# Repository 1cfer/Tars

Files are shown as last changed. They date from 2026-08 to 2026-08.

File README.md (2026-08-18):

# TARS — Sistema Modular de Monitoreo Ambiental Portátil basado en ESP32

Dispositivo modular de monitoreo ambiental para interiores, basado en ESP32, con pantalla OLED, navegación por botón físico y firmware gobernado por una máquina de estados. Envía sus datos periódicamente a la plataforma en la nube MOREHA, construida sobre el estándar FIWARE. Desarrollado en el Semillero AgeVital, Universidad Pontificia Bolivariana.







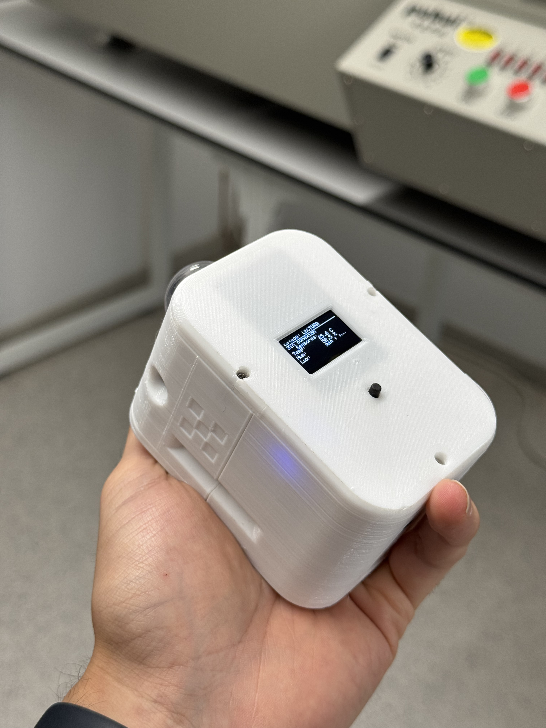
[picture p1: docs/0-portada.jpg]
TARS - vista de portada


## Descripción

TARS mide temperatura, humedad, luminosidad y ruido, y muestra los datos en tiempo real en una pantalla OLED con navegación por botón. El firmware usa una arquitectura de máquina de estados modular, y los datos se transmiten de forma segura hacia `moreha.com.co` mediante autenticación OAuth2 y paso por PEP Proxy, siguiendo el flujo de FIWARE (Keyrock → Wilma → Orion Context Broker).

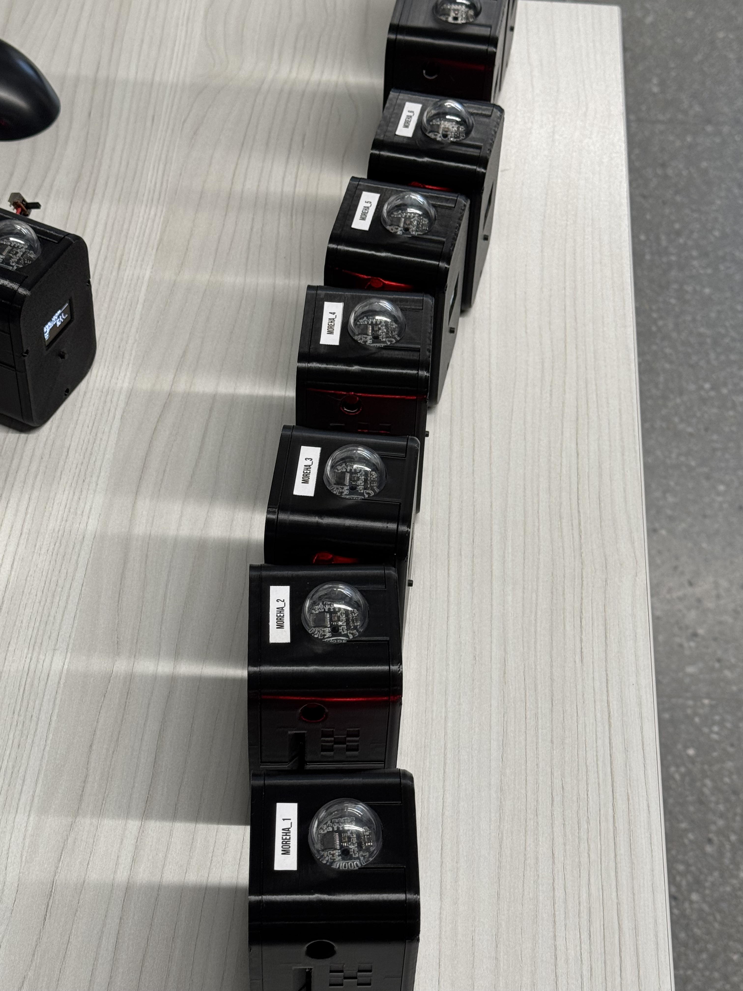
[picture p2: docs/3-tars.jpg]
Lote de dispositivos TARS ensamblados


## Características técnicas

- 🌡️ Temperatura y humedad (HDC1080, I2C)
- 💡 Luminosidad calibrada (DFRobot B-LUX-V30B, con filtro de mediana + descarte de picos)
- 🔊 Nivel de ruido (sensor analógico calibrado)
- 🧪 *(Experimental)* Calidad de aire — PM1.0 / PM2.5 / PM10 (DFRobot SEN0460), en evaluación energética y de laboratorio
- 🔌 Modularidad y expansión por bus I2C: espacio físico y líneas disponibles en la placa para incorporar nuevos sensores
- 🖥️ Pantalla OLED con navegación multi-pantalla por botón físico (pulsación corta/larga)
- 📡 Conectividad IoT industrial: envío periódico con autenticación OAuth2 y PEP Proxy

### Expansión por bus I2C

La placa reserva espacio físico y líneas de conexión libres para incorporar fácilmente un sensor adicional, siempre que use el protocolo I2C.

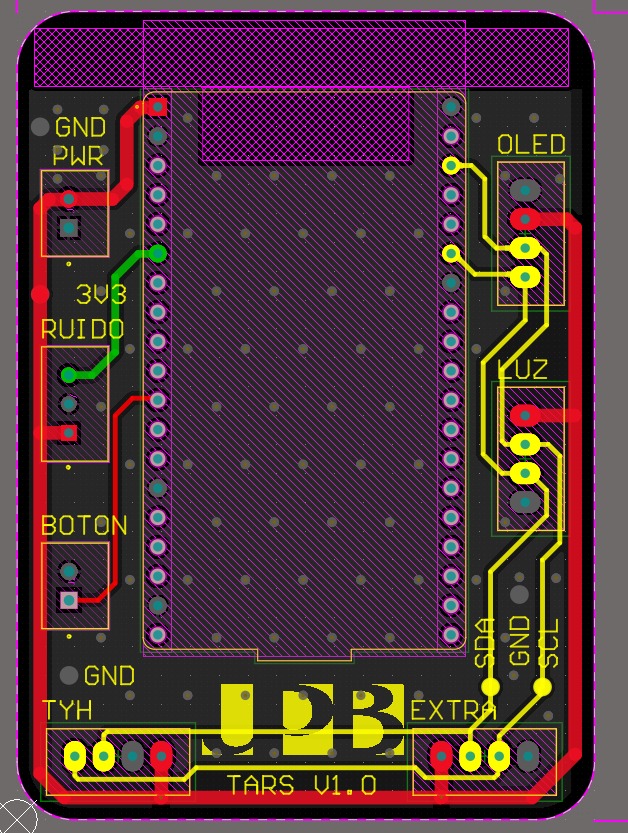
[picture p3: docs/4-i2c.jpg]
Puerto I2C libre para expansión de sensores


### Sensor de calidad de aire (experimental)

Integración en curso del sensor PM1.0 / PM2.5 / PM10 (DFRobot SEN0460), actualmente en fase de evaluación energética y de laboratorio.

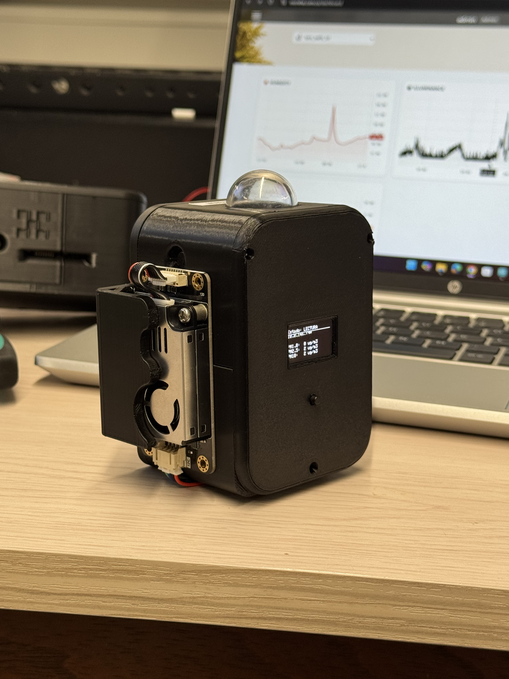
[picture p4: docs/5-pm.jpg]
TARS con sensor experimental de calidad de aire conectado


## Evolución del hardware

TARS partió de un prototipo de pruebas hasta llegar a la PCB con la que operan actualmente todos los dispositivos.

<table>
<tr>
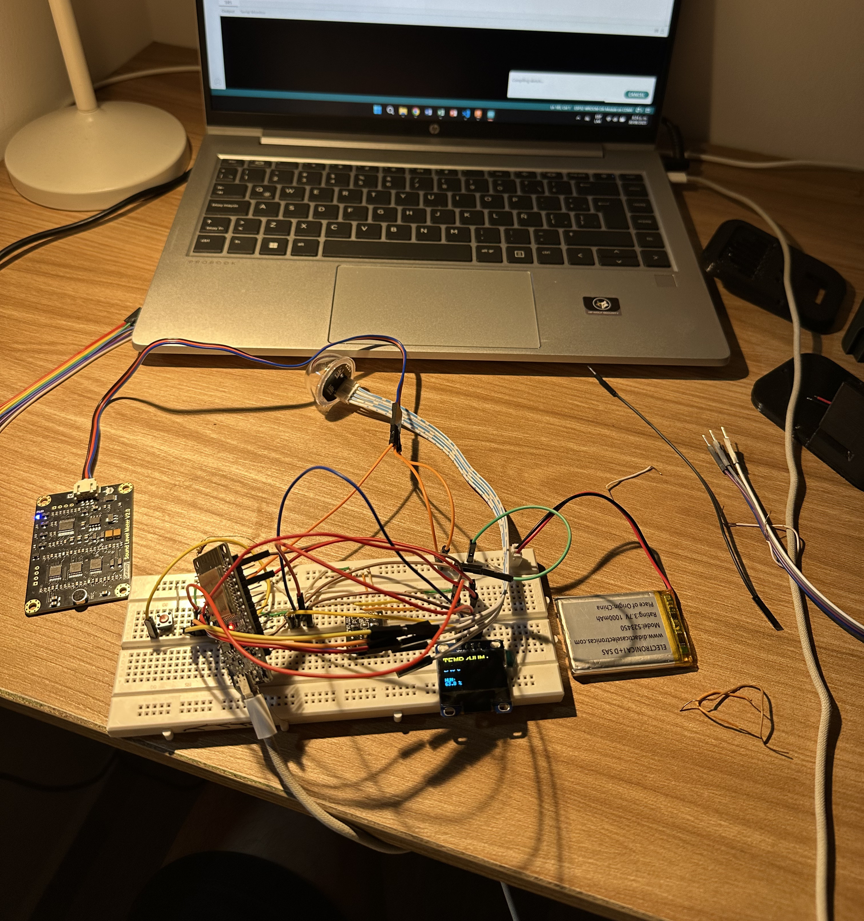
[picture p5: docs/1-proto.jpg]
Prototipo en breadboard
<td align="center"><br/><sub><strong>Fase 1</strong> — Prototipo inicial en breadboard, cableado suelto</sub></td>
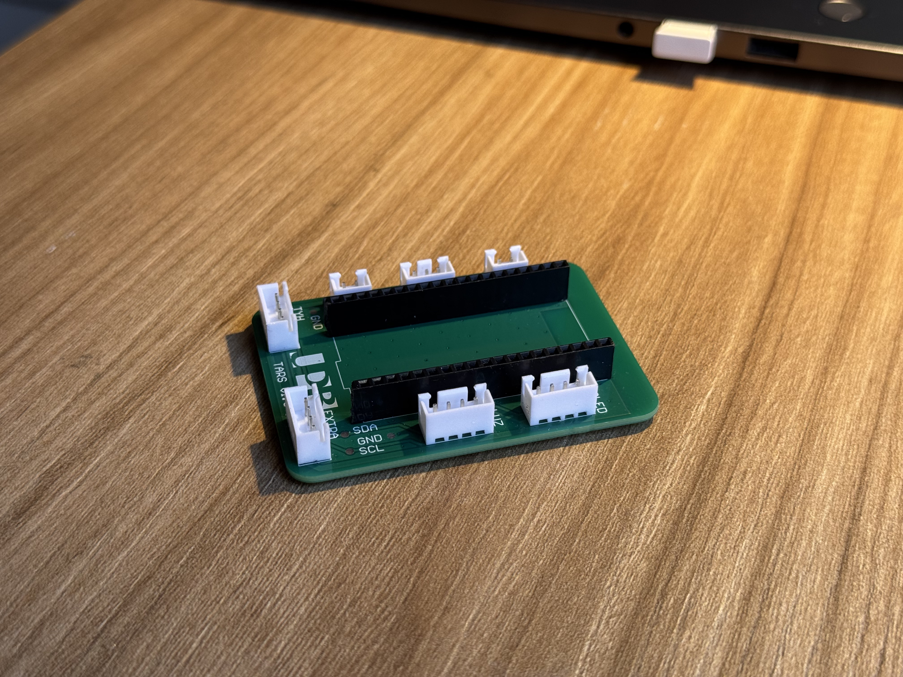
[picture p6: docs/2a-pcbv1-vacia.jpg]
PCB TARS actual sin componentes
<td align="center"><br/><sub><strong>Fase 2</strong> — PCB actual, sin componentes montados</sub></td>
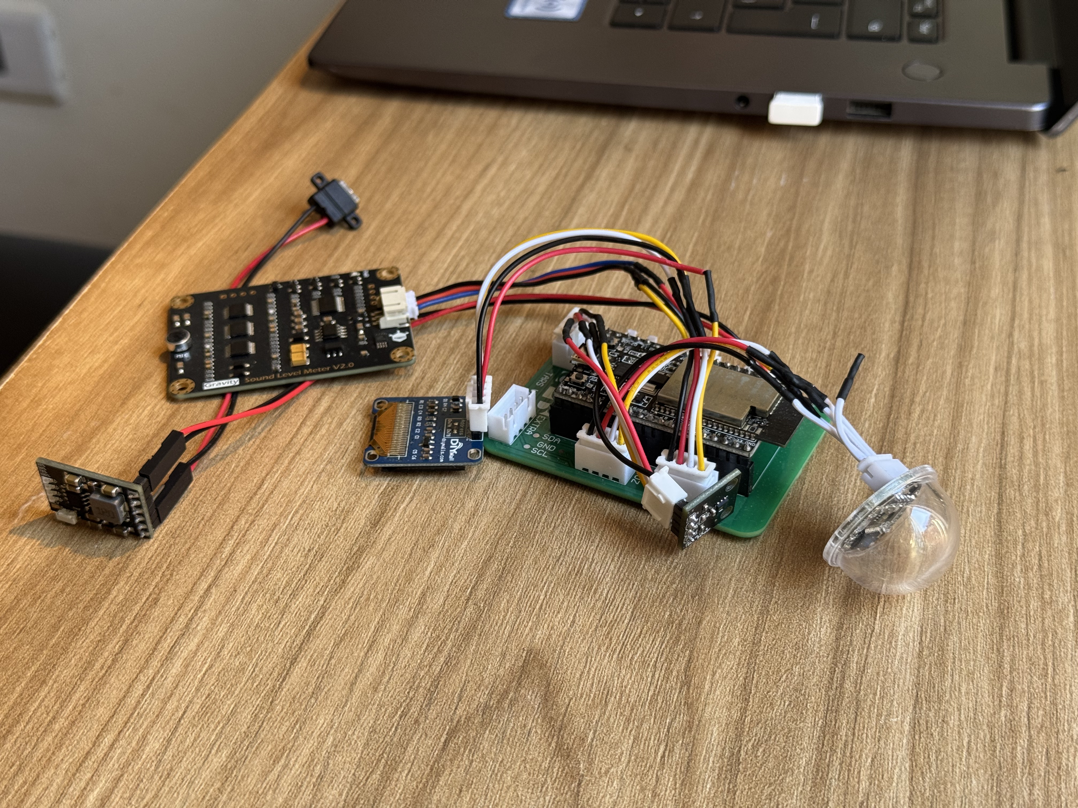
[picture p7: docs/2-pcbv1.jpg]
PCB TARS actual con componentes conectados
<td align="center"><br/><sub><strong>Fase 2</strong> — PCB actual, con sensores y componentes internos</sub></td>
</tr>
</table>

| Fase | Formato | Alimentación | Integración |
|---|---|---|---|
| 1. Prototipo | Protoboard | Externa / provisional | Ninguna, cableado expuesto |
| 2. PCB actual | Módulo ESP32 sobre headers | Batería LiPo 1000 mAh + UPS externa (UPS-LIPO-2) | Headers hembra, conectores JST |

La **PCB actual** es la primera placa diseñada para el proyecto y es la que usan hoy en día todos los dispositivos TARS construidos hasta la fecha: monta la ESP32 como módulo sobre headers hembra, enlaza los sensores mediante conectores JST, y se alimenta con una batería de polímero de litio de 1000 mAh gestionada por una UPS externa (UPS-LIPO-2).

### Carcasa

El dispositivo cuenta con una carcasa impresa en 3D en material **PLA**, diseñada a la medida de la PCB y los sensores.

<p align="center">
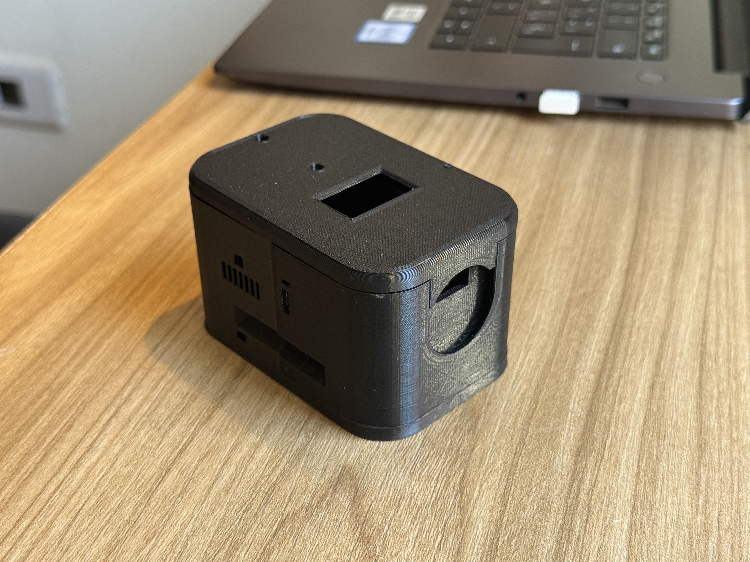
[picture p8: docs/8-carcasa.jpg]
Carcasa de TARS impresa en 3D en PLA, sin componentes
  
</p>

### TARS en funcionamiento

Un TARS operando en un laboratorio, con el sensor de luminosidad orientado hacia la ventana y conectado a la corriente.

<p align="center">
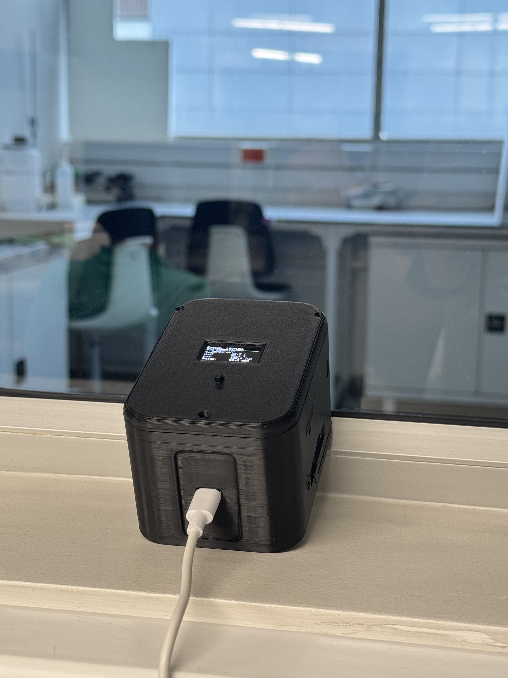
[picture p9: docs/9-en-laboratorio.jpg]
TARS en funcionamiento en un laboratorio, conectado a la corriente
  
</p>

## Arquitectura de firmware

El firmware corre sobre una **máquina de estados modular**:

```
StateMachine
├── EstadoINICIO        → conexión WiFi, primer boot
├── EstadoLECTURA        → lectura periódica de sensores + refresco de pantalla
├── EstadoENVIO           → autenticación OAuth2 + PATCH a Orion vía Wilma
└── EstadoDESARROLLADOR  → modo de diagnóstico y configuración
```

El procesamiento local de sensores incluye filtros digitales — **filtro de mediana** y **descarte de picos extremos** — aplicados especialmente al sensor de luminosidad, para evitar transiciones erróneas en pantalla causadas por lecturas espurias.

## Integración y protocolo FIWARE (MOREHA)

TARS transmite hacia `moreha.com.co` siguiendo el flujo de seguridad de FIWARE, en dos pasos.

**Paso 1 — Autenticación OAuth2 (Keyrock):**

```
POST http://moreha.com.co:7000/oauth2/token
Content-Type: application/x-www-form-urlencoded

grant_type=password
client_id=<CLIENT_ID>
client_secret=<CLIENT_SECRET>
username=<DEVICE_USERNAME>
password=<DEVICE_PASSWORD>
```

El dispositivo no envía datos directamente: primero solicita un `access_token` temporal al Identity Manager (Keyrock) usando sus credenciales.

**Paso 2 — Transmisión segura (PEP Proxy Wilma → Orion Context Broker):**

```
PATCH http://moreha.com.co:1027/v2/entities/{deviceId}/attrs
Authorization: Bearer <access_token>
Content-Type: application/json

{
  "temperature": { "value": 23.4, "type": "Number" },
  "humidity": { "value": 55.2, "type": "Number" },
  "noise": { "value": 41.0, "type": "Number" },
  "luminosity": { "value": 320, "type": "Number" }
}
```

Con el token obtenido, TARS envía el payload al proxy de seguridad **Wilma**, incluyendo la cabecera `Authorization: Bearer <token>`. Wilma valida el token contra Keyrock y, si es correcto, autoriza el paso hacia el **Orion Context Broker**, donde **QuantumLeap** y **CrateDB** gestionan el histórico de datos.

<p align="center">
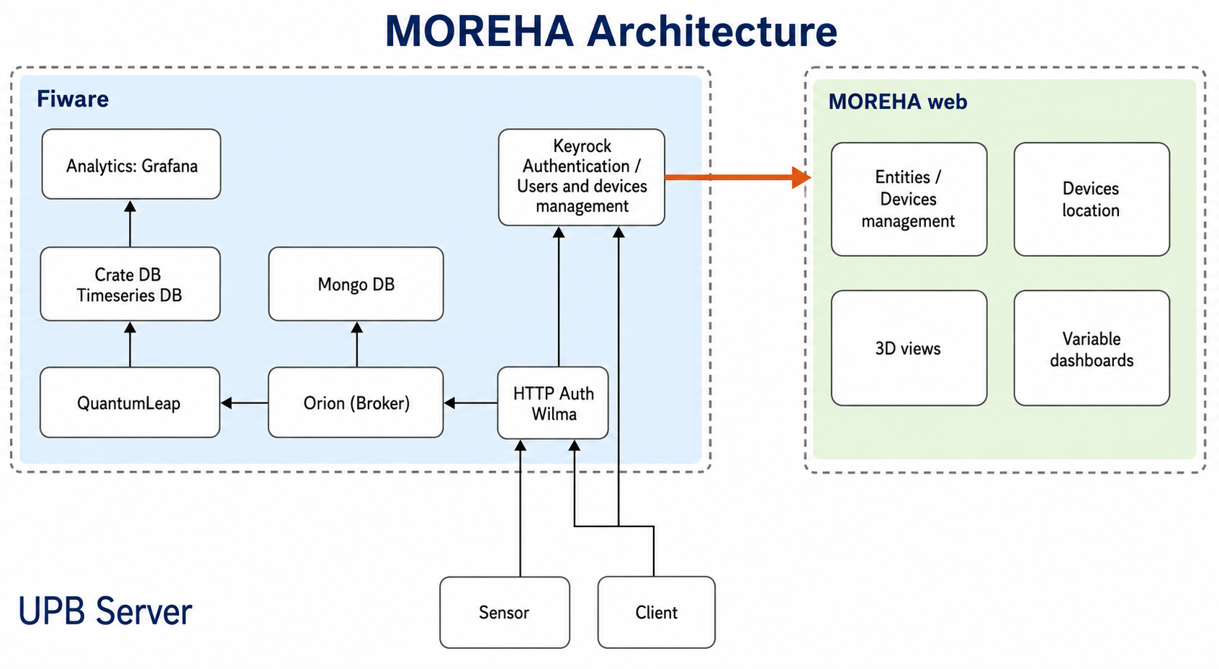
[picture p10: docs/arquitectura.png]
MOREHA Architecture - diagrama de bloques TARS y FIWARE
  
</p>

<p align="center">
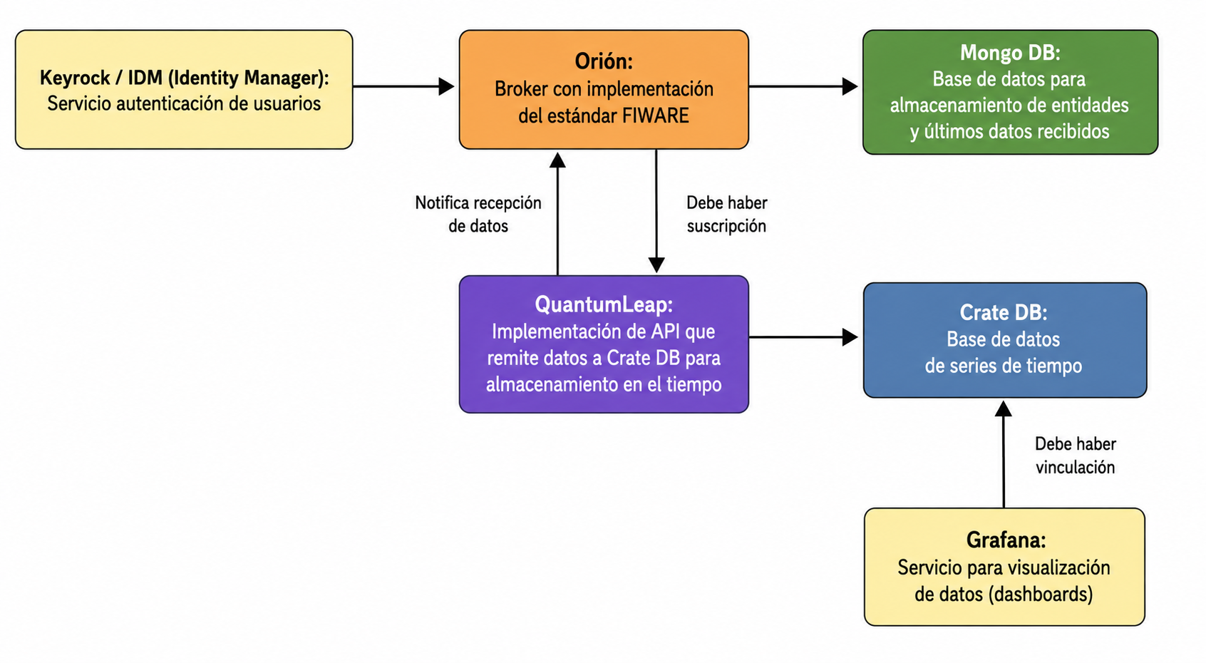
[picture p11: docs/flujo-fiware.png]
Flujo de suscripción y persistencia de datos FIWARE
  
</p>

## Plataforma web (visualización)

La plataforma **MOREHA** ([moreha.com.co](http://moreha.com.co)) ofrece gestión centralizada de dispositivos e históricos de las variables medidas.

<table>
<tr>
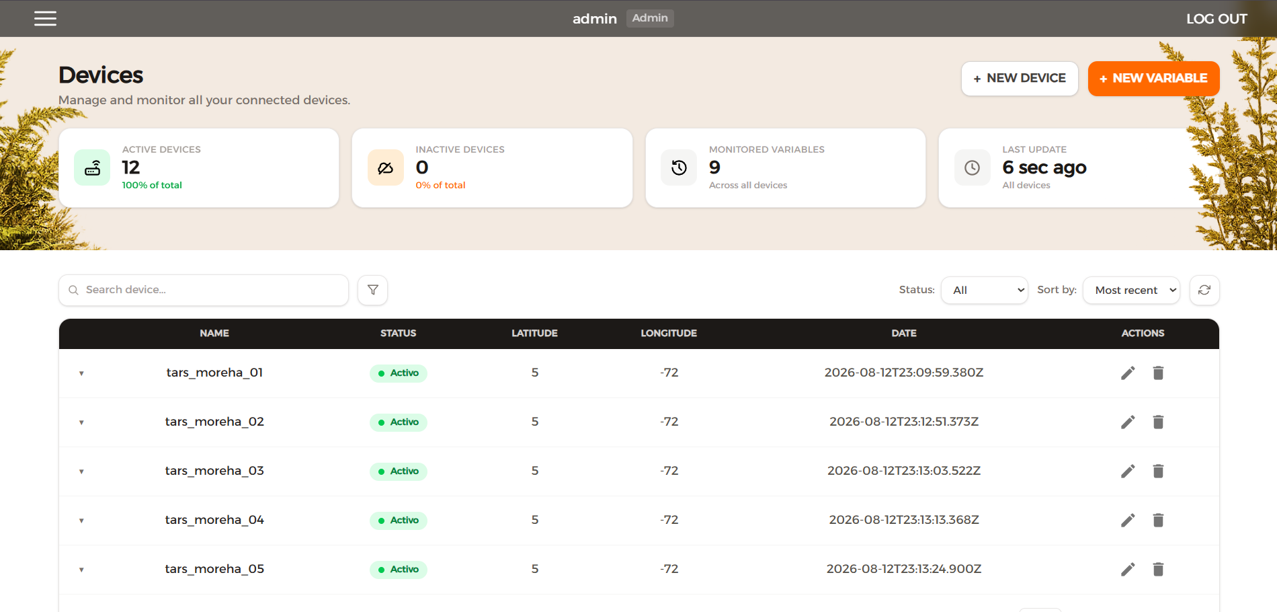
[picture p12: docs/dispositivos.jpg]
Tabla de dispositivos activos en MOREHA
<td align="center"><br/><sub>Gestión de dispositivos — <code>tars1</code> reportando humedad, temperatura, iluminancia, ruido y calidad del aire</sub></td>
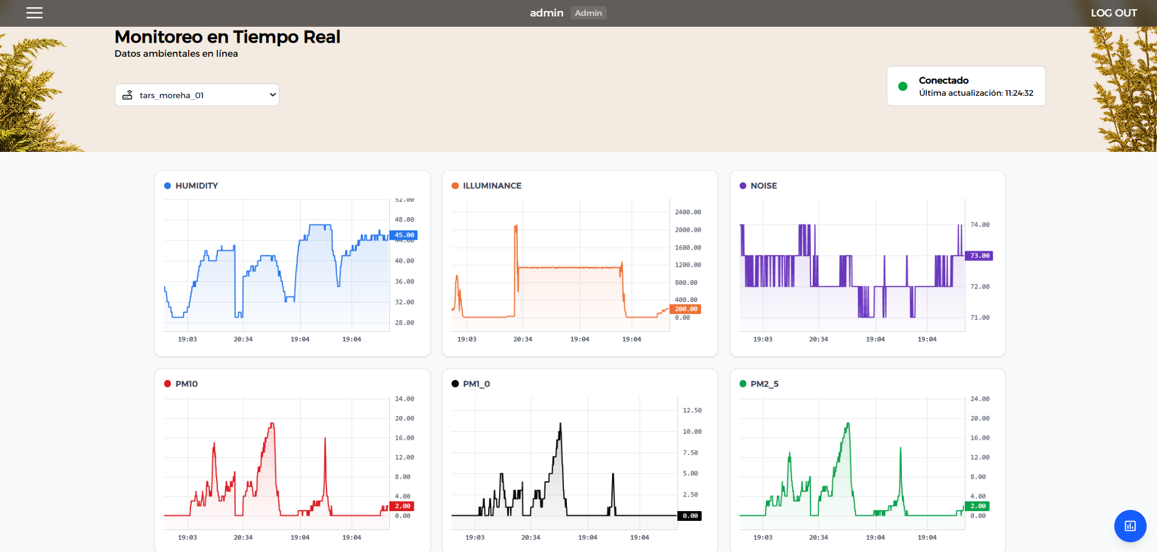
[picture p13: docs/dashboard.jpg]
Panel histórico de datos en MOREHA
<td align="center"><br/><sub>Histórico de humedad y temperatura en el dashboard</sub></td>
</tr>
</table>

## Guía de instalación y requisitos

### Librerías de Arduino necesarias

| Librería | Uso |
|---|---|
| `Adafruit GFX Library` | Renderizado gráfico base para la pantalla OLED |
| `Adafruit SSD1306` | Controlador del display OLED |
| `ArduinoJson` | Serialización/deserialización de payloads JSON |
| `ClosedCube_HDC1080` | Lectura del sensor de temperatura y humedad |
| `DFRobot_B_LUX_V30B` | Lectura del sensor de luminosidad |

### Pasos de configuración

1. Instala las librerías anteriores desde el Gestor de Librerías del IDE de Arduino.
2. Abre el sketch del firmware y selecciona la placa **ESP32** en `Herramientas > Placa`.
3. Carga el firmware al dispositivo.
4. En el primer arranque, conéctate al **portal cautivo local** que expone el dispositivo y configura ahí la red WiFi.
5. TARS reinicia automáticamente y comienza su ciclo normal (`EstadoINICIO` → `EstadoLECTURA` → `EstadoENVIO`).

## Próximos cambios

Se está desarrollando una nueva iteración de PCB (**v1.5**), actualmente **en fase de pruebas**, que integra de forma nativa todos los componentes en una sola placa: el microcontrolador ESP32 soldado directamente, el circuito de gestión de batería (UPS) embebido y un puerto USB-C nativo para carga y comunicación. Esto reduciría drásticamente el volumen del dispositivo respecto a la PCB actual, aunque todavía no reemplaza a la que usan los TARS en operación.

<p align="center">
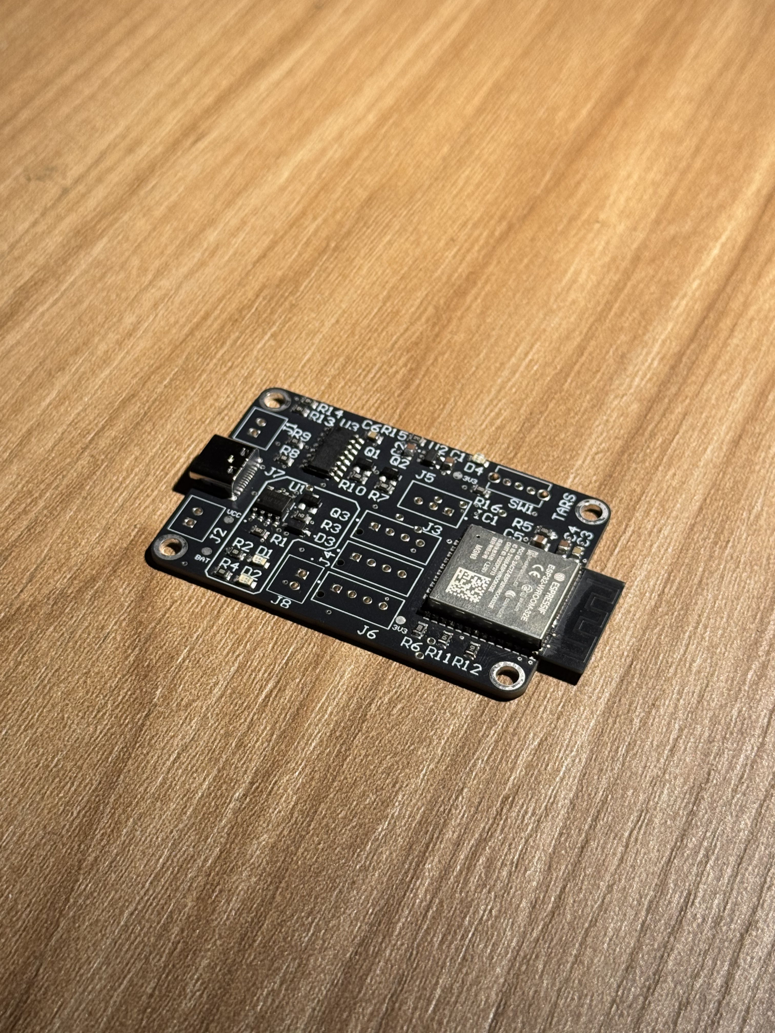
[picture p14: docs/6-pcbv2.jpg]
Nueva PCB v1.5 integrada, en fase de pruebas
  
  <br/>
  <sub>PCB v1.5 — en pruebas: ESP32, USB-C y UPS nativos en una sola placa</sub>
</p>

## Créditos

Desarrollado en el **Semillero AgeVital**, Universidad Pontificia Bolivariana.

- **Supervisión técnica:** Henry Andrade Caicedo
- **Desarrollo:** Fer Castro

## Licencia

MIT — ver [LICENSE](LICENSE)

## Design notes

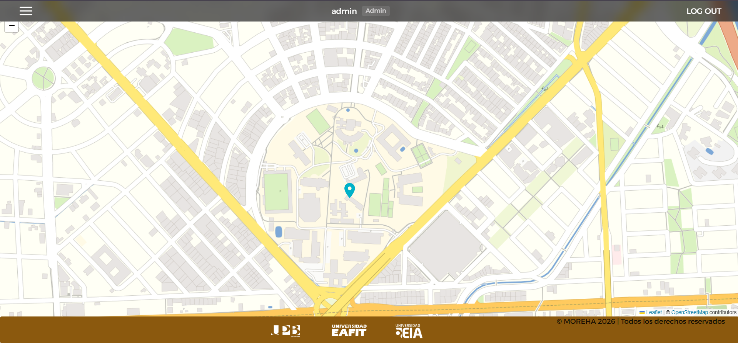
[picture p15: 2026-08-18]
docs/mapa.jpg

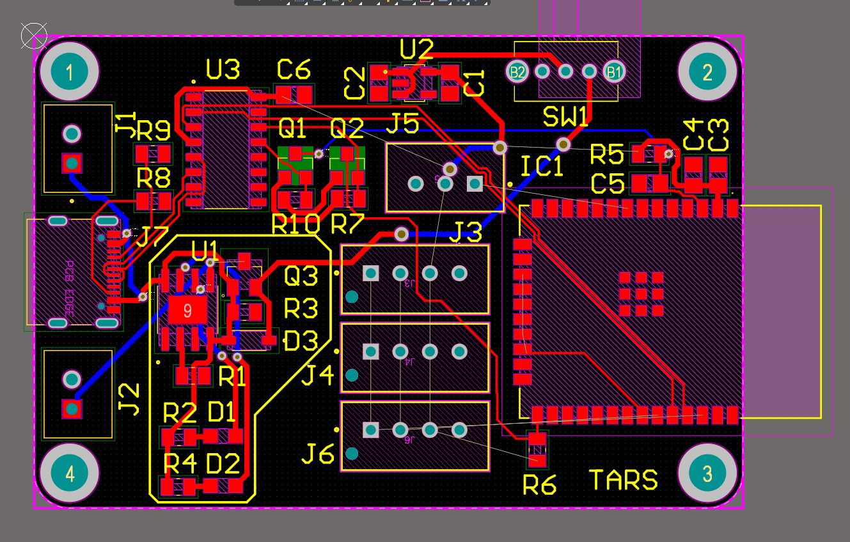
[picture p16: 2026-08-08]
docs/esquematico.jpeg

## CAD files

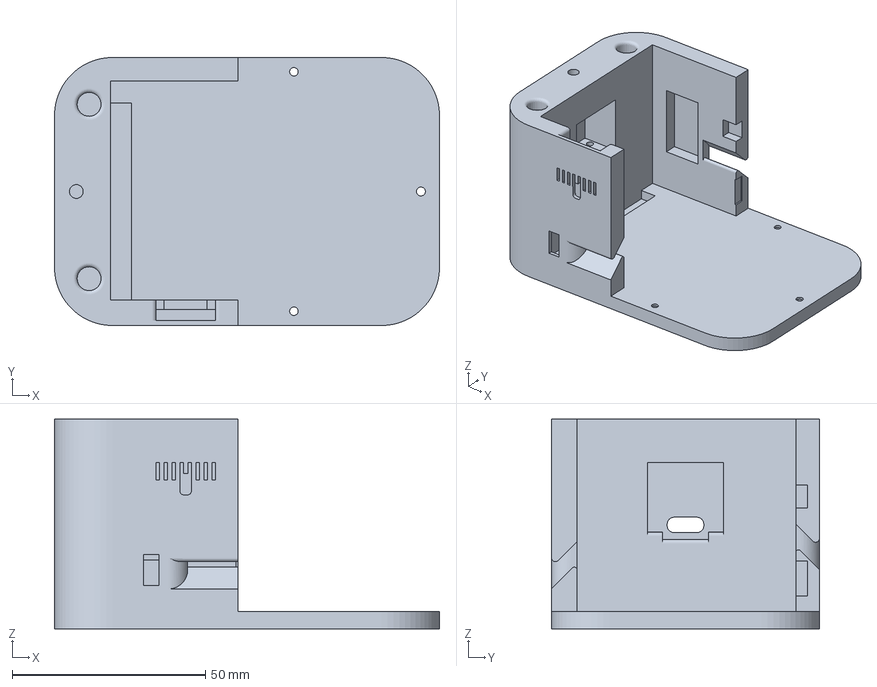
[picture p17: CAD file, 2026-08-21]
hardware/MAYOR_OG.3mf
99.7 x 69.4 x 54.3 mm

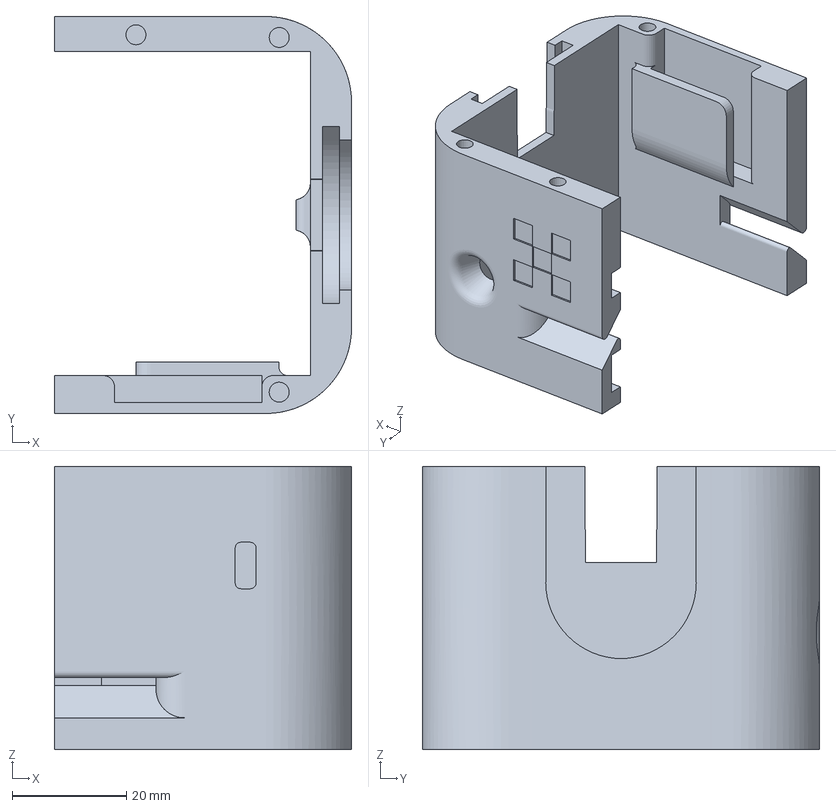
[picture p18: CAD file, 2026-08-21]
hardware/MENOR_OG.3mf
52.0 x 69.4 x 49.5 mm

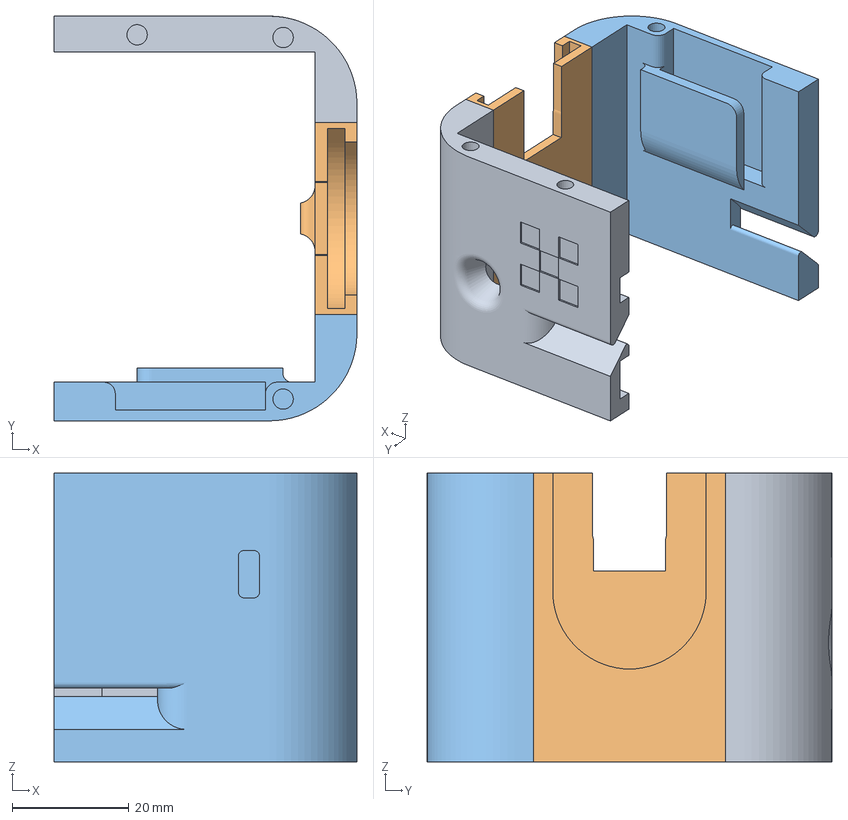
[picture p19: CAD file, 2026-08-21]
hardware/TARS_MENOR.3mf
52.0 x 69.4 x 49.5 mm
MENOR (1)
MENOR (2)
MENOR

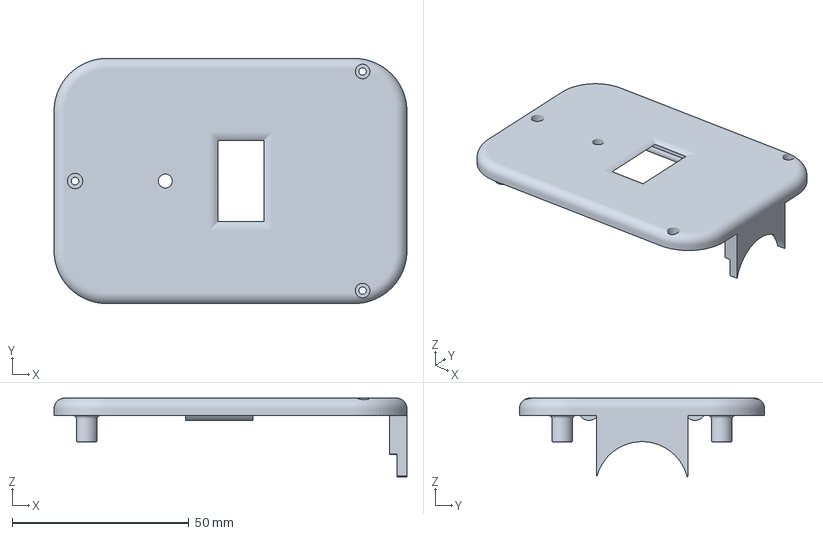
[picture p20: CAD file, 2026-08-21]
hardware/TARS_TOP.3mf
99.9 x 69.4 x 22.3 mm

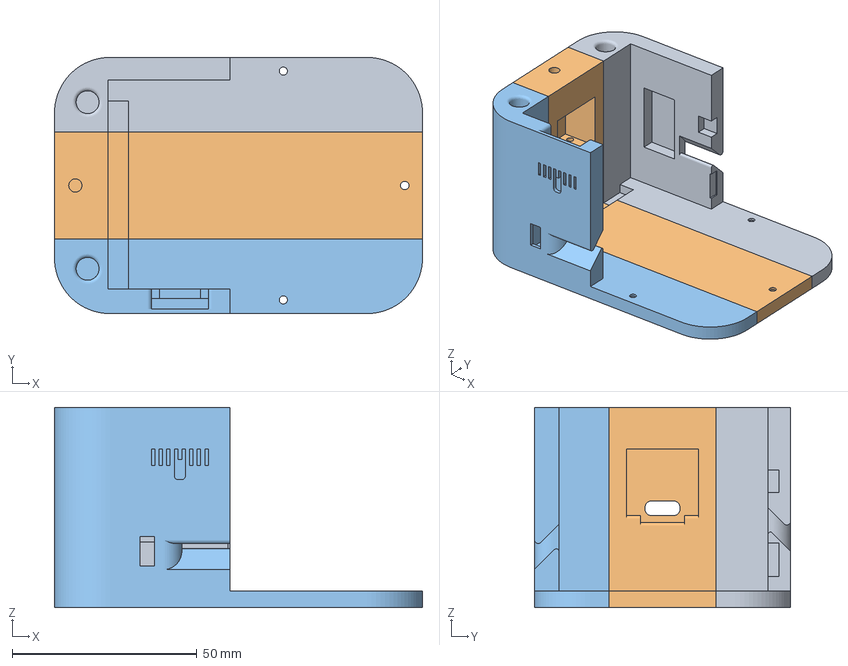
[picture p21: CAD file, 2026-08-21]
hardware/TARS_MAYOR.3mf
99.7 x 69.4 x 54.3 mm
MAYOR_BASE (4)
MAYOR_BASE (5)
MAYOR_BASE (7)

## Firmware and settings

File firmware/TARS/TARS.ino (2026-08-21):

#include <Adafruit_GFX.h> 
#include <Adafruit_SSD1306.h> 
#include <ArduinoJson.h> 
#include <DFRobot_B_LUX_V30B.h> 
#include <EEPROM.h> 
#include <ESPmDNS.h> 
#include <HTTPClient.h> 
#include <WebServer.h> 
#include <WiFi.h> 
#include <Wire.h> 

#include "AppConfig.h" 
#include "ButtonHandler.h" 
#include "ClosedCube_HDC1080.h" 
#include "DisplayManager.h" 
#include "Estados.h" 
#include "PayloadBuilder.h" 
#include "SensorManager.h" 
#include "State.h" 
#include "StateMachine.h" 
#include "TokenManager.h" 
#include "WiFiManager.h"

#define SCREEN_WIDTH 128 
#define SCREEN_HEIGHT 64 
#define BUTTON_PIN 27 

Adafruit_SSD1306 display(SCREEN_WIDTH, SCREEN_HEIGHT, &Wire, -1); 
ClosedCube_HDC1080 hdc1080; 
DFRobot_B_LUX_V30B luxSensor(&Wire, 5); // Tu librería preferida
WebServer server(80); 
AppConfig appConfig; 
WiFiManager wifiManager; 
TokenManager tokenManager; 
ButtonHandler buttonHandler(BUTTON_PIN); 
StateMachine stateMachine; 
SensorManager sensorManager; 

SET_LOOP_TASK_STACK_SIZE(16384); 

void setup() { 
  Serial.begin(115200); 
  Wire.begin(21, 22);
  Wire.setTimeOut(1000); 
  
  hdc1080.begin(0x40); 
  Wire.setClock(50000); 
  luxSensor.begin(); 
  analogReadResolution(12);

  if (!display.begin(SSD1306_SWITCHCAPVCC, 0x3C)) while (1); 

  buttonHandler.begin();
  appConfig.begin();
  sensorManager.begin();
  stateMachine.begin(new EstadoINICIO()); 
}

void loop() { 
  ButtonHandler::Event event = buttonHandler.update();

  if (event != ButtonHandler::NONE) { 
    // Actualizamos el reloj de interacción siempre que se presione algo
    stateMachine.clocks.ultima_interaccion = millis();
    
    // Si la pantalla estaba apagada, la despertamos
    if (!stateMachine.isDisplayOn) {
        stateMachine.isDisplayOn = true;
        stateMachine.needsUpdate = true;
        
        // REQUERIMIENTO: Si el evento fue un clic corto para despertar la pantalla, 
        // lo anulamos aquí mismo para que NO avance a la siguiente vista de sensores.
        if (event == ButtonHandler::SHORT_PRESS) {
            event = ButtonHandler::NONE; 
        }
    }
  }

  // Puente: Pasamos el evento a los estados para que ellos decidan qué hacer.
  // Si anulamos el clic corto arriba, a la máquina de estados llegará como "NONE"
  // y la pantalla se quedará exactamente donde la dejaste.
  stateMachine.currentEvent = event;
  stateMachine.update(); 
  stateMachine.currentEvent = ButtonHandler::NONE; // Limpiamos el evento
}

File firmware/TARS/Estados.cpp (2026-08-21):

#include "Estados.h"
#include <WiFiClientSecure.h>
#include <ESPmDNS.h>

#include "AppConfig.h" 
#include "DevWebOTA.h" 
#include "TokenManager.h" 
#include "WiFiManager.h"
#include "DisplayManager.h"

DevWebOTA *devWeb = nullptr;
extern Adafruit_SSD1306 display;
extern WebServer server;
extern SensorManager sensorManager;

// ======================================== 
// IMPLEMENTACIÓN ESTADO INICIO 
// ========================================
void EstadoINICIO::onEnter() { 
    Serial.println("===Entrando en Estado INICIO==="); 
    statemachine->flags.inicio = true; 
    firstRun = true; 
}

void EstadoINICIO::execute() { 
    if (!firstRun) return;

    if (!appConfig.isConfigured) { 
        Serial.println("[INICIO] Primer boot detectado — forzando modo DESARROLLADOR para setup"); 
        statemachine->flags.dev = true; 
        statemachine->ChangeState(new EstadoDESARROLLADOR()); 
        return; 
    }

    if (statemachine->flags.dev) { 
        Serial.println("Cambiando a Estado DESARROLLADOR desde INICIO"); 
        statemachine->ChangeState(new EstadoDESARROLLADOR()); 
        return; 
    }

    unsigned long now = millis(); 
    Serial.println("Estado: INICIO");

    if (wifiManager.connect(16)) { 
        Serial.println("[INICIO] WiFi listo para envío de datos"); 
        MDNS.begin(appConfig.hostname.c_str()); 
        Serial.printf("[mDNS] Activo en http://%s.local\n", appConfig.hostname.c_str()); 
    } else { 
        Serial.println("[INICIO] Sin WiFi, autoReconnect activo"); 
    }

    statemachine->flags.inicio = false; 
    statemachine->clocks.proximo_envio = now + appConfig.intervaloEnvio; 
    statemachine->flags.envio_programado = true;

    statemachine->ChangeState(new EstadoLECTURA()); 
    firstRun = false; 
}

void EstadoINICIO::onExit() { 
    Serial.println("===Saliendo de Estado INICIO==="); 
    statemachine->flags.inicio = false; 
    firstRun = false; 
}

const char *EstadoINICIO::getName() { return "INICIO"; }

// ======================================== 
// IMPLEMENTACIÓN ESTADO LECTURA 
// ========================================
void EstadoLECTURA::onEnter() { 
    Serial.println("===Entrando en Estado LECTURA==="); 
    statemachine->flags.lectura = true; 
    statemachine->flags.inicio = false; 
    statemachine->flags.envio = false; 
}

void EstadoLECTURA::execute() { 
    unsigned long now = millis();
    ButtonHandler::Event btn = statemachine->currentEvent;

    // CORRECCIÓN: % 4 PARA CICLAR LAS 4 PANTALLAS
    if (btn == ButtonHandler::SHORT_PRESS) {
        statemachine->screenMode = (statemachine->screenMode + 1) % 4; 
        statemachine->needsUpdate = true;
    } else if (btn == ButtonHandler::VERY_LONG_PRESS_4S) {
        statemachine->ChangeState(new EstadoDESARROLLADOR());
        return;
    }

    if (statemachine->isDisplayOn && (now - statemachine->clocks.ultima_interaccion > appConfig.tiempoInactividad)) { 
        display.clearDisplay(); 
        display.display(); 
        statemachine->isDisplayOn = false; 
    }

    if (statemachine->needsUpdate && statemachine->isDisplayOn) { 
        updateDisplay(); 
        statemachine->needsUpdate = false; 
    }

    if (now - statemachine->clocks.tiempo_lectura >= appConfig.intervaloLectura) { 
        sensorManager.read(); 
        if (statemachine->isDisplayOn) { updateDisplay(); } 
        statemachine->clocks.tiempo_lectura = now; 
    }

    if (statemachine->flags.envio_programado && (long)(now - statemachine->clocks.proximo_envio) >= 0) { 
        statemachine->ChangeState(new EstadoENVIO()); 
        return; 
    }

    wifiManager.maintainConnection(); 
}

void EstadoLECTURA::onExit() { 
    Serial.println("===Saliendo de Estado LECTURA==="); 
    statemachine->flags.lectura = false; 
}

const char *EstadoLECTURA::getName() { return "LECTURA"; }

// ======================================== 
// IMPLEMENTACIÓN ESTADO ENVIO 
// ========================================
void EstadoENVIO::onEnter() { 
    Serial.println("=== ENTRANDO A ESTADO: ENVIO ==="); 
    statemachine->flags.envio = true; 
    statemachine->flags.inicio = false; 
    statemachine->flags.lectura = false;

    if (statemachine->isDisplayOn) { 
        display.clearDisplay(); 
        displayStateInfo("ENVIO"); 
        display.display(); 
    } 
}

void EstadoENVIO::execute() { 
    unsigned long now = statemachine->clocks.tiempo_actual;
    ButtonHandler::Event btn = statemachine->currentEvent;

    // Permitir ir al modo desarrollador si se traba el envío
    if (btn == ButtonHandler::VERY_LONG_PRESS_4S) {
        statemachine->ChangeState(new EstadoDESARROLLADOR());
        return;
    }

    if (!wifiManager.isConnected()) { 
        Serial.println("Sin conexión WiFi, posponiendo envío"); 
        statemachine->clocks.proximo_envio = now + appConfig.intervaloReintento; 
        statemachine->flags.envio_programado = true; 
        statemachine->ChangeState(new EstadoLECTURA()); 
        return; 
    }

    if (!appConfig.skipToken && !tokenManager.ensureValidToken()) { 
        Serial.println("[ENVIO] No se pudo obtener token, posponiendo envío"); 
        statemachine->clocks.proximo_envio = now + appConfig.intervaloReintento; 
        statemachine->flags.envio_programado = true; 
        statemachine->ChangeState(new EstadoLECTURA()); 
        return; 
    }

    SensorData avg = sensorManager.getAverages(); 
    sensorManager.resetAccumulator();

    // EXCLUIDO EL SENSOR PM: Construimos el payload solo con Temperatura, Humedad, Luz y Ruido
    String payload = construirPayload(avg.temp, avg.hum, avg.lux, avg.dbValue); 
    Serial.println("[ENVIO] Payload JSON:"); 
    Serial.println(payload);

    WiFiClientSecure *client = new WiFiClientSecure(); 
    if (!client) { 
        statemachine->clocks.proximo_envio = now + appConfig.intervaloReintento; 
        statemachine->flags.envio_programado = true; 
        statemachine->ChangeState(new EstadoLECTURA()); 
        return; 
    } 
    client->setInsecure();

    HTTPClient http; 
    http.begin(*client, appConfig.serverUrl); 
    http.addHeader("Content-Type", "application/json"); 
    if (!appConfig.skipToken) { 
        http.addHeader("Authorization", "Bearer " + tokenManager.getToken()); 
    }

    int httpResponseCode = http.PATCH(payload);

    if (httpResponseCode >= 200 && httpResponseCode < 300) { 
        Serial.printf("✓ Envío exitoso, código: %d\n", httpResponseCode); 
    } else if (httpResponseCode == 401) { 
        tokenManager.clear(); 
    }

    http.end(); 
    delete client; 
    statemachine->clocks.proximo_envio = now + appConfig.intervaloEnvio; 
    statemachine->flags.envio_programado = true; 
    statemachine->ChangeState(new EstadoLECTURA()); 
}

void EstadoENVIO::onExit() { 
    statemachine->flags.envio = false; 
}

const char *EstadoENVIO::getName() { return "ENVIO"; }
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

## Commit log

2026-08-08 Actualizacion de README
2026-08-08 Corregir nombres de imagenes y actualizar README con las 5 fotos
2026-08-18 Revise PCB version and add future changes details
    Updated PCB version references and added upcoming changes section.
2026-08-18 Nuevas fotos para incluir en el repositorio
2026-08-18 Delete docs/4-i2c.jpeg
    La extensión de la foto era la incorrecta
2026-08-18 Update PCB description in README
2026-08-18 Resumen de Tars en PDF
2026-08-21 feat(tars): actualizacion de UI OLED, gestion multi-wifi y exclusion de sensor PM
    [MAYOR_OG.3mf, MENOR_OG.3mf, TARS_MAYOR.3mf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]
